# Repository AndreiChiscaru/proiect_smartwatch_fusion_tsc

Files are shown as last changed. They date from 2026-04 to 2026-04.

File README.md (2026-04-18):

# InkTime - Open Source Smartwatch 

Acest repository conține fișierele de design hardware (faza EVT) pentru **InkTime**, un smartwatch accesibil și open-source, bazat pe microcontrolerul nRF52840. Proiectul a fost dezvoltat de la specificații la PCB asamblat, incluzând schema electrică, design-ul plăcii și integrarea componentelor mecanice în carcasa 3D personalizată.

---

## 1. Schematic si PCB

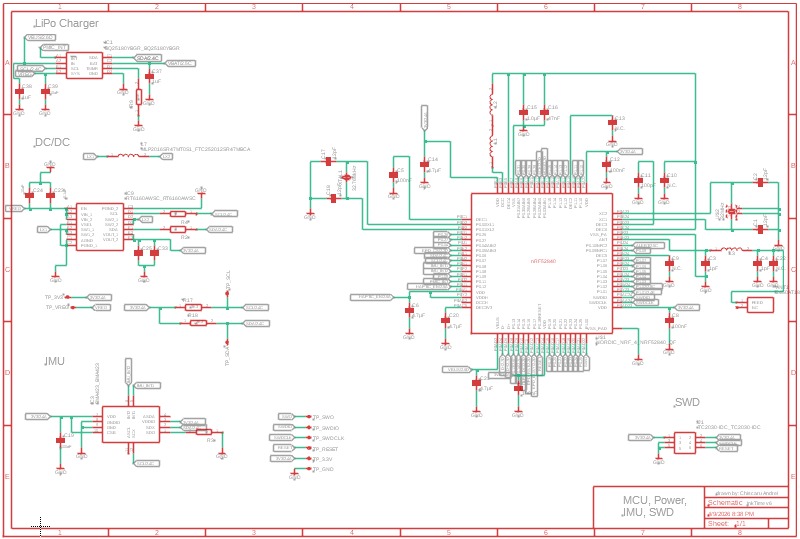
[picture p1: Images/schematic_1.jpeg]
Schematic1
 

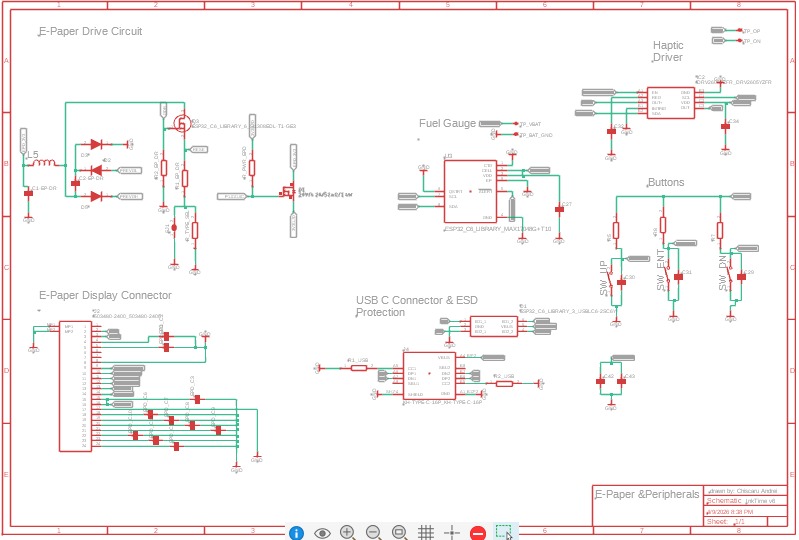
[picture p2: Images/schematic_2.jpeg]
Schematic2
 

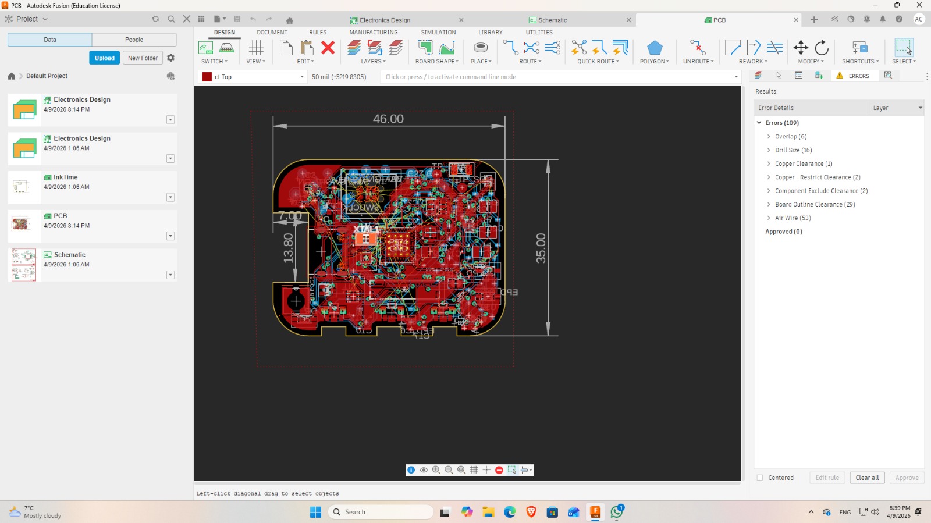
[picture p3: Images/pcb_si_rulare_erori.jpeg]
PCB
 

*(Notă: Arhitectura de bază folosește nRF52840 ca unitate centrală, comunicând periferic cu senzorii și display-ul, având un management de putere dedicat.)*

---

## 2. Descrierea Funcționalității Hardware

Sistemul este construit în jurul SoC-ului **nRF52840**, ales pentru conectivitatea Bluetooth Low Energy (BLE) și eficiența energetică excelentă.

**Module și Interfețe Integrate:**
* **Display E-Paper:** Conectat la microcontroler prin interfața **SPI** (MOSI, SCK, CS), asigurând un consum extrem de redus de energie, consumând curent doar în timpul refresh-ului ecranului.
* **IMU (Senzor de mișcare):** Pentru detecția gesturilor (ex. ridicarea mâinii). Comunică exclusiv prin interfața **I2C** (SDA, SCL).
* **Feedback Haptic (Shaker):** Un motor de vibrații controlat printr-un pin **PWM/GPIO**, utilizat pentru notificări silențioase.
* **Interfață Utilizator:** 3 butoane fizice tip push-button conectate cu rezistențe de pull-up interne.
* **Managementul Energiei:** * Sistemul este alimentat de o baterie Li-Po lipită direct pe pad-urile plăcii (fără conector JST) pentru a respecta constrângerea de spațiu pe axa Z.
  * Încărcarea se face prin portul **USB-C** folosind un circuit dedicat de management al bateriei.
  * Tensiunea este stabilizată la **3V3** printr-un convertor LDO/DC-DC pentru restul circuitelor.

---

## 3. Maparea Pinilor (nRF52840 Pinout)

Mai jos este prezentată alocarea pinilor pentru componentele periferice principale, optimizată pentru a minimiza încrucișările de trasee pe PCB:

| Componentă / Modul | Pini nRF52840 utilizați | Funcție / Interfață |
| :--- | :--- | :--- |
| **Display E-Paper** | P0.13, P0.15, P0.17, P0.20, P0.22 | SPI (SCK, MOSI, CS, DC, RST) |
| **Senzor IMU** | P0.26, P0.27 | I2C (SDA, SCL) |
| **Buton 1 (Up)** | P1.13 | GPIO (Input Pull-up) |
| **Buton 2 (Select)** | P1.14 | GPIO (Input Pull-up) |
| **Buton 3 (Down)** | P1.15 | GPIO (Input Pull-up) |
| **Motor Vibrații (Shaker)**| P0.11 | GPIO (Output / PWM) |
| **Monitorizare Baterie**| P0.02 | ADC (Analog In) |

---

## 4. Bill of Materials (BOM) Extras

Lista componentelor principale utilizate în acest design:

| Componentă | Capsulă / Pachet | Funcție | Link Achiziție / Datasheet |
| :--- | :--- | :--- | :--- |
| **nRF52840-QIAA-R** | QFN-73 | Microcontroler principal (SoC) | [JLC Parts](https://jlcpcb.com/parts) |
| **LSM6DS3TR** | LGA-14 | IMU (Accelerometru + Giroscop) | [JLC Parts](https://jlcpcb.com/parts) |
| **BQ24040DSQR** | WSON-8 | IC Management Încărcare Baterie | [JLC Parts](https://jlcpcb.com/parts) |
| **AP2112K-3.3** | SOT-23-5 | Regulator Tensiune 3.3V (LDO) | [JLC Parts](https://jlcpcb.com/parts) |
| **Conector FPC** | 24-pin, 0.5mm | Conector Display E-Paper | [JLC Parts](https://jlcpcb.com/parts) |
| **Pasive (C, R)** | 0201 / 0402 | Decuplare (100nF) și Pull-up (10k) | [JLC Parts](https://jlcpcb.com/parts) |

---

## 5. Design Log & Decizii de Proiectare (Issue-uri Acceptate)

Pentru a respecta cerințele tehnice și deadline-ul etapei EVT, au fost luate următoarele decizii de design:

* **Structura PCB:** Placa are **grosimea impusă de 1mm** și a fost realizată pe 2 layere (Top și Bottom). Amplasarea componentelor a fost făcută exclusiv pe layer-ul TOP. S-a realizat un plan de masă continuu pe ambele layere, unite prin via stitching.
* **Reguli de Rutare:** Liniile de alimentare (VCC, 3V3, VBAT, VUSB) au fost rutate manual respectând grosimea de **0.3mm**. Semnalele de date au folosit grosimea de **0.15mm**, evitându-se unghiurile drepte.
* **Zona RF:** Sub antena Bluetooth de 2.4GHz s-a aplicat Polygon Pour Cutout pe toate straturile. Nu există plan de masă sau trasee sub antenă, pentru a preveni ecranarea.
* **[BUG ACCEPTAT] Erori DRC și Acoperire Autorouter (89.2%):** Datorită densității masive de componente din jurul portului USB și a limitărilor mecanice foarte stricte impuse de carcasa 3D (mufele și butoanele au coordonate fixe), s-au acceptat temporar mici erori de tip *Overlap/Clearance* la condensatoarele 0201 aferente decuplării. Din același motiv de spațiu fizic limitat, Autorouter-ul a atins o acoperire maximă de 89.2%. Am decis să păstrez aceste câteva trasee nerutate pe Top în loc să mut componente pe Bottom, pentru a nu complica masiv viitorul proces de asamblare (Pick & Place pe ambele fețe crește mult costurile). Aceste conexiuni vor fi optimizate manual în sprint-ul pentru DVT.

---

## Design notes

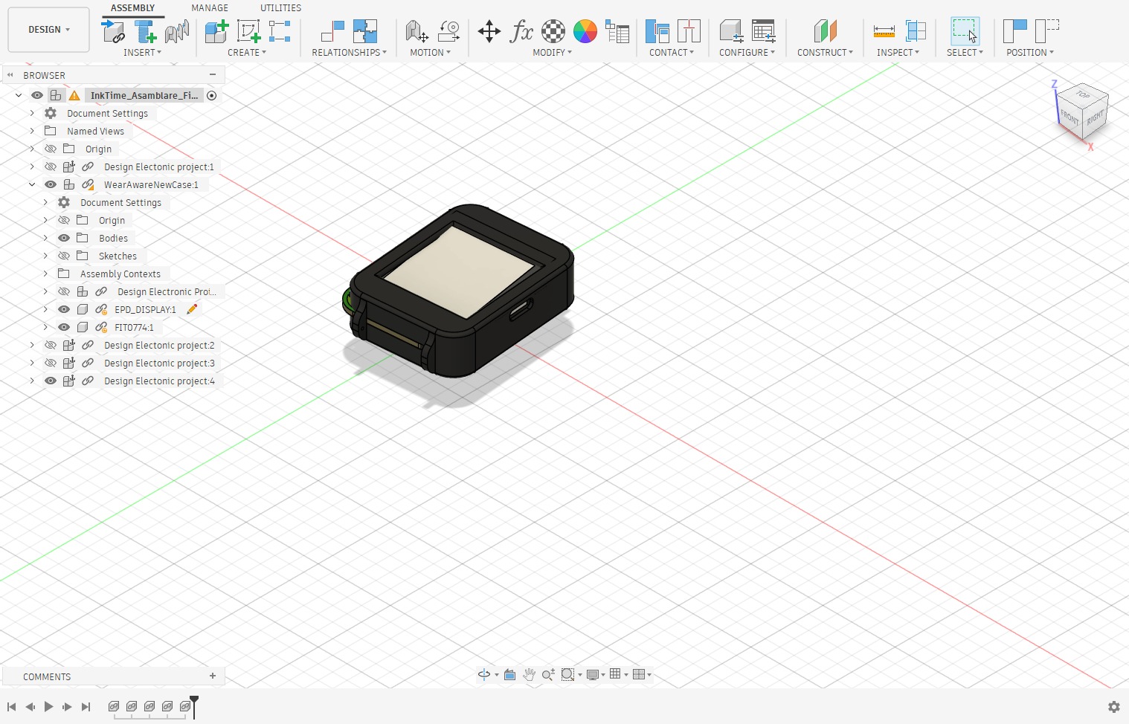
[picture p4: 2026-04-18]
Images/asamblare.jpeg

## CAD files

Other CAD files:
Mechanical/InkTime_Asamblare_Fin.f3z

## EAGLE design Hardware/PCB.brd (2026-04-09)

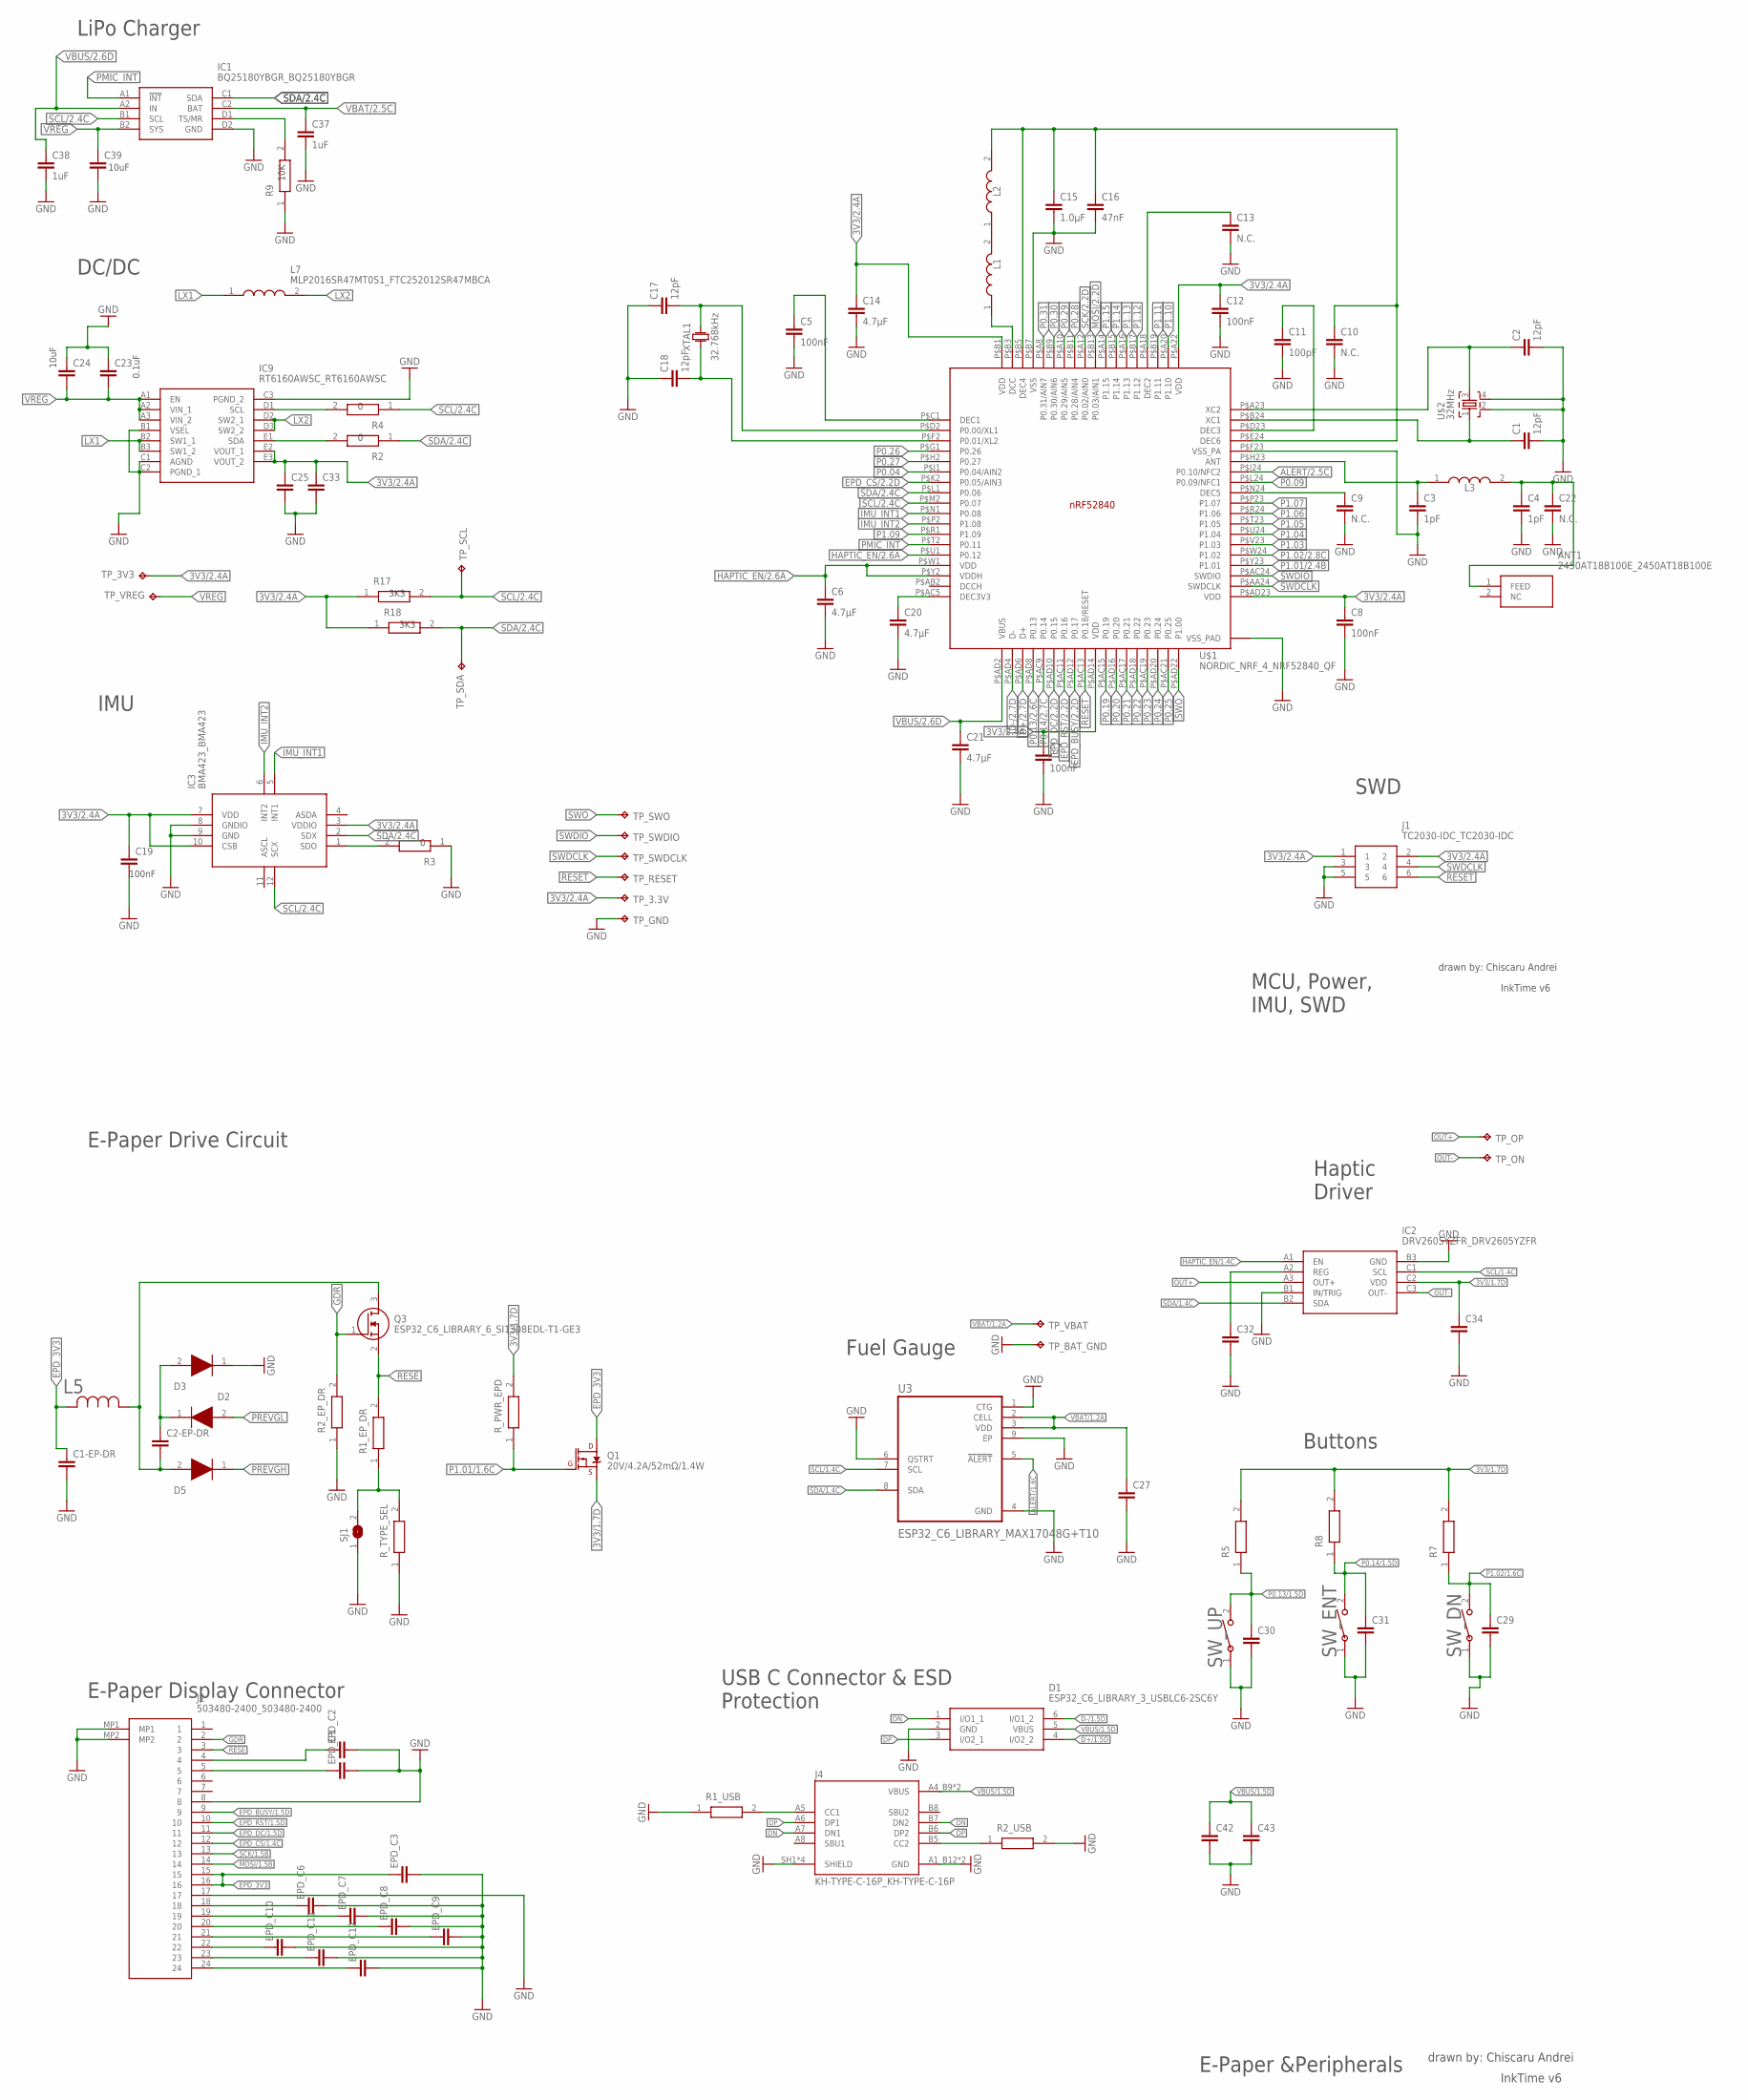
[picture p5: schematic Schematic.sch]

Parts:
ANT1: 2450AT18B100E_2450AT18B100E; 2450AT18B100E_ANTC3216X140N
C1, C2, C17, C18: 12pF; NORDIC_NRF_3_RESC0201_L
C1-EP-DR, C24, C39: 10uF; NORDIC_NRF_3_RESC0201_L
C2-EP-DR: 4.7uF/25V; NORDIC_NRF_3_RESC0201_L
C3, C4: 1pF; NORDIC_NRF_3_RESC0201_L
C5, C7, C8, C12, C19: 100nF; NORDIC_NRF_3_RESC0201_L
C6, C14, C20, C21: 4.7µF; NORDIC_NRF_3_RESC0201_L
C9, C10, C13, C22: N.C.; NORDIC_NRF_3_RESC0201_L
C11: 100pF; NORDIC_NRF_3_RESC0201_L
C15: 1.0µF; NORDIC_NRF_3_RESC0201_L
C16: 47nF; NORDIC_NRF_3_RESC0201_L
C23, C27, C34, C42: 0.1uF; NORDIC_NRF_3_RESC0201_L
C25, C33: 22uF; NORDIC_NRF_3_RESC0201_L
C29, C30, C31, C32, C37, C38: 1uF; NORDIC_NRF_3_RESC0201_L
C43: 4.7uF; NORDIC_NRF_3_RESC0201_L
D1: ESP32_C6_LIBRARY_3_USBLC6-2SC6Y; ESP32_C6_LIBRARY_3_SOT95P280X145-6N
D2, D3, D5: ESP32_C6_LIBRARY_5_MBR0530; ESP32_C6_LIBRARY_5_SOD3716X135N
EPD_C1, EPD_C2, EPD_C6, EPD_C7, EPD_C8, EPD_C9, EPD_C10, EPD_C11, EPD_C12: 1uF/50V; NORDIC_NRF_3_RESC0201_L
EPD_C3: 0.1uF/50V; NORDIC_NRF_3_RESC0201_L
IC1: BQ25180YBGR_BQ25180YBGR; BQ25180YBGR_BGA8C40P2X4_100X155X50
IC2: DRV2605YZFR_DRV2605YZFR; DRV2605YZFR_BGA9C50P3X3_144X144X62
IC3: BMA423_BMA423
IC9: RT6160AWSC_RT6160AWSC; RT6160AWSC_BGA15C40P3X5_140X230X60
J1: TC2030-IDC_TC2030-IDC; TC2030-IDC_TC2030IDC
J2: 503480-2400_503480-2400; 503480-2400_5034802400
J4: KH-TYPE-C-16P_KH-TYPE-C-16P; KH-TYPE-C-16P_KINGHELM_KH-TYPE-C-16P
L1: 10µH; MLP2016SR47MT0S1_INDC2016X100N
L2: 15nH; MLP2016SR47MT0S1_INDC2016X100N
L3: 3.9nH; MLP2016SR47MT0S1_INDC2016X100N
L5: 68uH; ESP32_C6_LIBRARY_2_IND_4828-WE-TPC_WRE
L7: MLP2016SR47MT0S1_FTC252012SR47MBCA; MLP2016SR47MT0S1_INDC2016X100N
Q1: 20V/4.2A/52mΩ/1.4W; ESP32_C6_LIBRARY_4_ESP32_C6_LIBRARY_4_ESP32_C6_LIBRARY_4_ES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
Q3: ESP32_C6_LIBRARY_6_SI1308EDL-T1-GE3; ESP32_C6_LIBRARY_6_SOT65P210X110-3N
R1_EP_DR: 0.47; CPF0201D7K68C1_0201
R1_USB, R2_USB: 5K1; CPF0201D7K68C1_0201
R2, R3, R4: 0; CPF0201D7K68C1_0201
R2_EP_DR, R5, R7, R8, R9: 10K; CPF0201D7K68C1_0201
R17, R18: 3K3; CPF0201D7K68C1_0201
R_PWR_EPD: 10K; CPF0201D7K68C1_0201
R_TYPE_SEL: 2.2; CPF0201D7K68C1_0201
SJ1: ESP32_C6_LIBRARY_7_JUMPER_SJ
SW_DN: 2025-10-22_07-23-44_LIBRARY_EVP-AKE31ASW_EVP-AKE3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; 2025-10-22_07-23-44_LIBRARY_SW_EVP-AKE31A_PAN
SW_ENT: 2025-10-22_07-23-44_LIBRARY_EVP-AKE31ASW_EVP-AKE3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; 2025-10-22_07-23-44_LIBRARY_SW_EVP-AKE31A_PAN
SW_UP: 2025-10-22_07-23-44_LIBRARY_EVP-AKE31ASW_EVP-AKE3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; 2025-10-22_07-23-44_LIBRARY_SW_EVP-AKE31A_PAN
TP_3.3V, TP_3V3: HECTOR_WATCH_1_TPTP20R; HECTOR_WATCH_1_TP20R
TP_BAT_GND: HECTOR_WATCH_1_TPTP20R; HECTOR_WATCH_1_TP20R
TP_GND: HECTOR_WATCH_1_TPTP20R; HECTOR_WATCH_1_TP20R
TP_ON: HECTOR_WATCH_1_TPTP20R; HECTOR_WATCH_1_TP20R
TP_OP: HECTOR_WATCH_1_TPTP20R; HECTOR_WATCH_1_TP20R
TP_RESET: HECTOR_WATCH_1_TPTP20R; HECTOR_WATCH_1_TP20R
TP_SCL: HECTOR_WATCH_1_TPTP20R; HECTOR_WATCH_1_TP20R
TP_SDA: HECTOR_WATCH_1_TPTP20R; HECTOR_WATCH_1_TP20R
TP_SWDCLK: HECTOR_WATCH_1_TPTP20R; HECTOR_WATCH_1_TP20R
TP_SWDIO: HECTOR_WATCH_1_TPTP20R; HECTOR_WATCH_1_TP20R
TP_SWO: HECTOR_WATCH_1_TPTP20R; HECTOR_WATCH_1_TP20R
TP_VBAT: HECTOR_WATCH_1_TPTP20R; HECTOR_WATCH_1_TP20R
TP_VREG: HECTOR_WATCH_1_TPTP20R; HECTOR_WATCH_1_TP20R
U3: ESP32_C6_LIBRARY_MAX17048G+T10; ESP32_C6_LIBRARY_SON50P200X200X80-9N
U$1: NORDIC_NRF_4_NRF52840_QF; NORDIC_NRF_4_AQFN50P700X700X85_HS-74N
U$2: 32MHz; NORDIC_NRF_BT-XTAL_2016_N
XTAL1: 32.768kHz; XTAL_ABS07-32.768KHZ-T

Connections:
3V3/1.7D: C34.1, IC2.C2 (VDD), Q1.2 (S), R5.2, R7.2, R8.2, R_PWR_EPD.2
3V3/2.4A: C7.1, C8.1, C12.1, C14.1, C19.1, C25.1, C33.1, IC3.3 (VDDIO), IC3.7 (VDD), IC3.10 (CSB), IC9.E2 (VOUT_1), IC9.E3 (VOUT_2), J1.1, R17.1, R18.1, TP_3.3V.TP, TP_3V3.TP, U$1.P$A22 (VDD), U$1.P$AD14 (VDD), U$1.P$AD23 (VDD), U$1.P$B1 (VDD)
ALERT/1.6C: U3.5 (!ALERT)
ALERT/2.5C: U$1.P$J24 (P0.10/NFC2)
D+/1.5D: D1.4 (I/O2_2)
D+/2.7D: U$1.P$AD6 (D+)
D-/1.5D: D1.6 (I/O1_2)
D-/2.7D: U$1.P$AD4 (D-)
DN: D1.1 (I/O1_1), J4.A7 (DN1), J4.B7 (DN2)
DP: D1.3 (I/O2_1), J4.A6 (DP1), J4.B6 (DP2)
EPD_3V3: C1-EP-DR.1, EPD_C3.1, J2.15, J2.16, L5.2, Q1.3 (D)
EPD_BUSY/1.5D: J2.9
EPD_BUSY/2.2D: U$1.P$AD12 (P0.17)
EPD_CS/1.4C: J2.12
EPD_CS/2.2D: U$1.P$K2 (P0.05/AIN3)
EPD_DC/1.5D: J2.11
EPD_DC/2.2D: U$1.P$AD10 (P0.15)
EPD_RST/1.5D: J2.10
EPD_RST/2.2D: U$1.P$AC11 (P0.16)
GDR: J2.2, Q3.1 (G), R2_EP_DR.2
GND: C1.2, C1-EP-DR.2, C2.2, C3.2, C4.2, C5.2, C6.2, C7.2, C8.2, C9.2, C10.2, C11.2, C12.2, C13.2, C14.2, C15.2, C16.2, C17.1, C18.1, C19.2, C20.2, C21.2, C22.2, C23.1, C24.1, C25.2, C27.2, C29.2, C30.2, C31.2, C32.2, C33.2, C34.2, C37.2, C38.2, C39.2, C42.2, C43.2, D1.2 (GND), D3.1 (K), EPD_C1.2, EPD_C2.2, EPD_C3.2, EPD_C6.2, EPD_C7.2, EPD_C8.2, EPD_C9.2, EPD_C10.2, EPD_C11.2, EPD_C12.2, IC1.D2 (GND), IC2.B1 (IN/TRIG), IC2.B3 (GND), IC3.8 (GNDIO), IC3.9 (GND), IC9.B1 (VSEL), IC9.C1 (AGND), IC9.C2 (PGND_1), IC9.C3 (PGND_2), J1.3, J1.5, J2.8, J2.17, J2.MP1, J2.MP2, J4.A1_B12 (GND), J4.A12_B1 (GND), J4.SH1 (SHIELD), J4.SH2 (SHIELD), J4.SH3 (SHIELD), J4.SH4 (SHIELD), R1_USB.1, R2_EP_DR.1, R2_USB.2, R3.1, R9.1, R_TYPE_SEL.1, SJ1.1, SW_DN.1, SW_ENT.1, SW_UP.1, TP_BAT_GND.TP, TP_GND.TP, U3.1 (CTG), U3.4 (GND), U3.6 (QSTRT), U3.9 (EP), U$1.P$74 (VSS_PAD), U$1.P$75 (VSS_PAD), U$1.P$76 (VSS_PAD), U$1.P$77 (VSS_PAD), U$1.P$78 (VSS_PAD), U$1.P$79 (VSS_PAD), U$1.P$80 (VSS_PAD), U$1.P$81 (VSS_PAD), U$1.P$82 (VSS_PAD), U$1.P$83 (VSS_PAD), U$1.P$84 (VSS_PAD), U$1.P$85 (VSS_PAD), U$1.P$86 (VSS_PAD), U$1.P$87 (VSS_PAD), U$1.P$88 (VSS_PAD), U$1.P$89 (VSS_PAD), U$1.P$90 (VSS_PAD), U$1.P$B7 (VSS), U$1.P$F23 (VSS_PA), U$2.2, U$2.4
HAPTIC_EN/1.4C: IC2.A1 (EN)
HAPTIC_EN/2.6A: C6.1, U$1.P$U1 (P0.12), U$1.P$W1 (VDD), U$1.P$Y2 (VDDH)
IMU_INT1: IC3.5 (INT1), U$1.P$N1 (P0.08)
IMU_INT2: IC3.6 (INT2), U$1.P$P2 (P1.08)
LX1: IC9.B2 (SW1_1), IC9.B3 (SW1_2), L7.1
LX2: IC9.D2 (SW2_1), IC9.D3 (SW2_2), L7.2
MOSI/1.5B: J2.14
MOSI/2.2D: U$1.P$B13 (P0.03/AIN1)
unnamed: EPD_C2.1, J2.4
unnamed: L1.1, U$1.P$B3 (DCC)
unnamed: IC1.D1 (TS/MR), R9.2
unnamed: C10.1, C15.1, C16.1, L2.2, U$1.P$B5 (DEC4), U$1.P$E24 (DEC6)
unnamed: IC9.E1 (SDA), R2.2
unnamed: EPD_C1.1, J2.5
unnamed: IC9.D1 (SCL), R4.2
unnamed: J4.A5 (CC1), R1_USB.2
unnamed: R1_EP_DR.1, R_TYPE_SEL.2, SJ1.2
unnamed: EPD_C6.1, J2.18
unnamed: IC3.1 (SDO), R3.2
unnamed: EPD_C7.1, J2.19
unnamed: EPD_C8.1, J2.20
unnamed: C2-EP-DR.2, D5.2 (A), L5.1, Q3.3 (D)
unnamed: C2-EP-DR.1, D2.1 (K), D3.2 (A)
unnamed: EPD_C9.1, J2.21
unnamed: EPD_C10.1, J2.22
unnamed: EPD_C11.1, J2.23
unnamed: C13.1, U$1.P$A18 (DEC2)
unnamed: EPD_C12.1, J2.24
unnamed: J4.B5 (CC2), R2_USB.1
unnamed: L1.2, L2.1
unnamed: C32.1, IC2.A2 (REG)
unnamed: C11.1, U$1.P$D23 (DEC3)
unnamed: C9.1, U$1.P$N24 (DEC5)
unnamed: C20.1, U$1.P$AC5 (DEC3V3)
unnamed: C5.1, U$1.P$C1 (DEC1)
unnamed: C2.1, U$1.P$A23 (XC2), U$2.3
unnamed: C1.1, U$1.P$B24 (XC1), U$2.1
unnamed: C3.1, L3.1, U$1.P$H23 (ANT)
unnamed: C17.2, U$1.P$D2 (P0.00/XL1), XTAL1.2
unnamed: ANT1.1 (FEED), C4.1, C22.1, L3.2
unnamed: C18.2, U$1.P$F2 (P0.01/XL2), XTAL1.1
OUT+: IC2.A3 (OUT+), TP_OP.TP
OUT-: IC2.C3 (OUT-), TP_ON.TP
P0.04: U$1.P$J1 (P0.04/AIN2)
P0.09: U$1.P$L24 (P0.09/NFC1)
P0.13/1.5D: C30.1, R5.1, SW_UP.2
P0.13/2.6C: U$1.P$AD8 (P0.13)
P0.14/1.5D: C31.1, R8.1, SW_ENT.2
P0.14/2.7C: U$1.P$AC9 (P0.14)
P0.19: U$1.P$AC15 (P0.19)
P0.20: U$1.P$AD16 (P0.20)
P0.21: U$1.P$AC17 (P0.21)
P0.22: U$1.P$AD18 (P0.22)
P0.23: U$1.P$AC19 (P0.23)
P0.24: U$1.P$AD20 (P0.24)
P0.25: U$1.P$AC21 (P0.25)
P0.26: U$1.P$G1 (P0.26)
P0.27: U$1.P$H2 (P0.27)
P0.28: U$1.P$B11 (P0.28/AIN4)
P0.29: U$1.P$A10 (P0.29/AIN5)
P0.30: U$1.P$B9 (P0.30/AIN6)
P0.31: U$1.P$A8 (P0.31/AIN7)
P1.01/1.6C: Q1.1 (G), R_PWR_EPD.1
P1.01/2.4B: U$1.P$Y23 (P1.01)
P1.02/1.6C: C29.1, R7.1, SW_DN.2
P1.02/2.8C: U$1.P$W24 (P1.02)
P1.03: U$1.P$V23 (P1.03)
P1.04: U$1.P$U24 (P1.04)
P1.05: U$1.P$T23 (P1.05)
P1.06: U$1.P$R24 (P1.06)
P1.07: U$1.P$P23 (P1.07)
P1.09: U$1.P$R1 (P1.09)
P1.10: U$1.P$A20 (P1.10)
P1.11: U$1.P$B19 (P1.11)
P1.12: U$1.P$B17 (P1.12)
P1.13: U$1.P$A16 (P1.13)
P1.14: U$1.P$B15 (P1.14)
P1.15: U$1.P$A14 (P1.15)
PMIC_INT: IC1.A1 (!INT), U$1.P$T2 (P0.11)
PREVGH: D5.1 (K)
PREVGL: D2.2 (A)
RESE: J2.3, Q3.2 (S), R1_EP_DR.2
RESET: J1.6, TP_RESET.TP, U$1.P$AC13 (P0.18/RESET)
SCK/1.5B: J2.13
SCK/2.2D: U$1.P$A12 (P0.02/AIN0)
SCL/1.4C: IC2.C1 (SCL), U3.7 (SCL)
SCL/2.4C: IC1.B1 (SCL), IC3.12 (SCX), R4.1, R17.2, TP_SCL.TP, U$1.P$M2 (P0.07)
SDA/1.4C: IC2.B2 (SDA), U3.8 (SDA)
SDA/2.4C: IC1.C1 (SDA), IC3.2 (SDX), R2.1, R18.2, TP_SDA.TP, U$1.P$L1 (P0.06)
SWDCLK: J1.4, TP_SWDCLK.TP, U$1.P$AA24 (SWDCLK)
SWDIO: TP_SWDIO.TP, U$1.P$AC24 (SWDIO)
SWO: TP_SWO.TP, U$1.P$AD22 (P1.00)
VBAT/1.2A: C27.1, TP_VBAT.TP, U3.2 (CELL), U3.3 (VDD)
VBAT/2.5C: C37.1, IC1.C2 (BAT)
VBUS/1.5D: C42.1, C43.1, D1.5 (VBUS), J4.A4_B9 (VBUS), J4.A9_B4 (VBUS)
VBUS/2.6D: C21.1, C38.1, IC1.A2 (IN), U$1.P$AD2 (VBUS)
VREG: C23.2, C24.2, C39.1, IC1.B2 (SYS), IC9.A1 (EN), IC9.A2 (VIN_1), IC9.A3 (VIN_2), TP_VREG.TP

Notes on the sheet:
LiPo Charger
10uF
10K
DC/DC
3K3
0.1uF
IMU
100nF
SWD
MCU, Power, IMU, SWD
drawn by: Chiscaru Andrei
InkTime v6
E-Paper Drive Circuit
E-Paper Display Connector
Haptic Driver
Fuel Gauge
Buttons
USB C Connector & ESD Protection
E-Paper &Peripherals

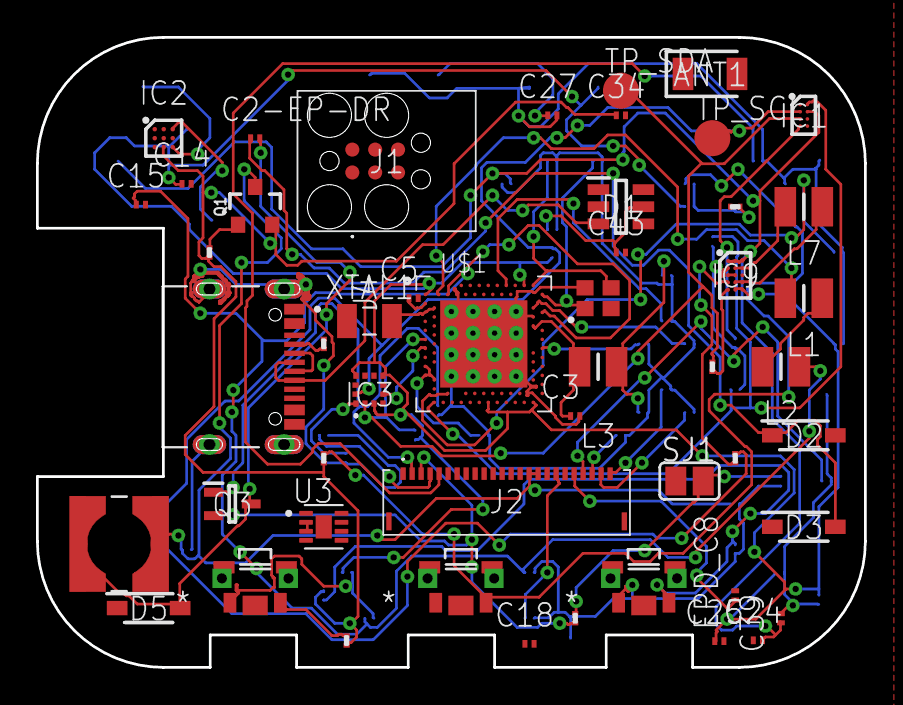
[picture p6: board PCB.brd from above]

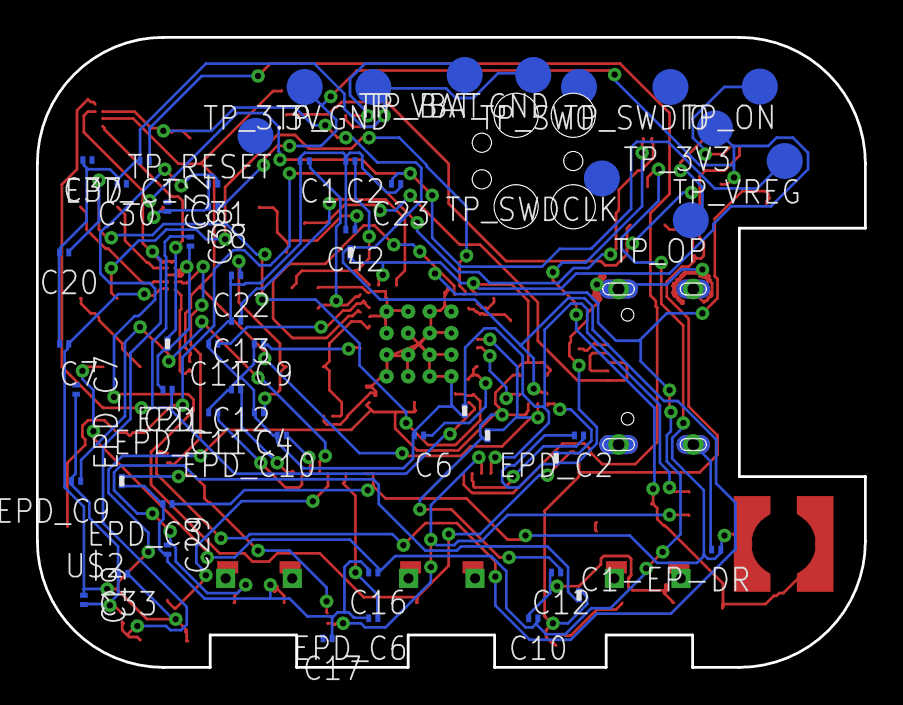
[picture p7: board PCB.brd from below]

Board: 2 copper layers, 46.0 x 35.0 mm, 105 parts (55 on the bottom side), 66 nets.

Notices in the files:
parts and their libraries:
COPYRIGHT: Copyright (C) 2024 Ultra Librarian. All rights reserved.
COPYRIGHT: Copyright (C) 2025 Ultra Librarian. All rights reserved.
